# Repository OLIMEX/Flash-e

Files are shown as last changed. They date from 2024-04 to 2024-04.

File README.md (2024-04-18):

# Flash-e
External eMMC and SPI Flash module

https://www.olimex.com/Products/OLinuXino/Accessories/Flash-e32Gs16M/

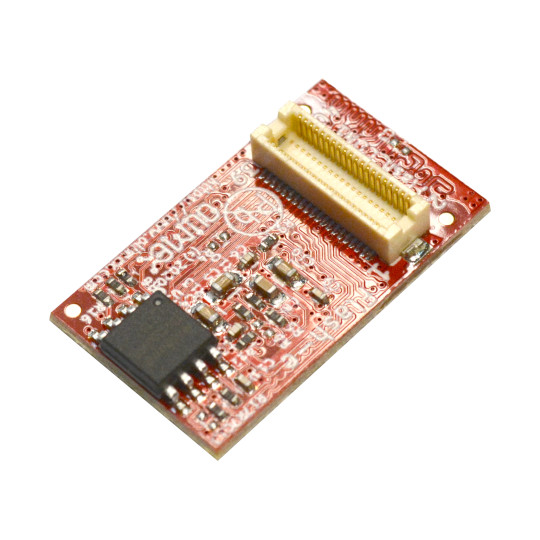
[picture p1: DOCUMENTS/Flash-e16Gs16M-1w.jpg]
Flash-e16Gs16M-1w

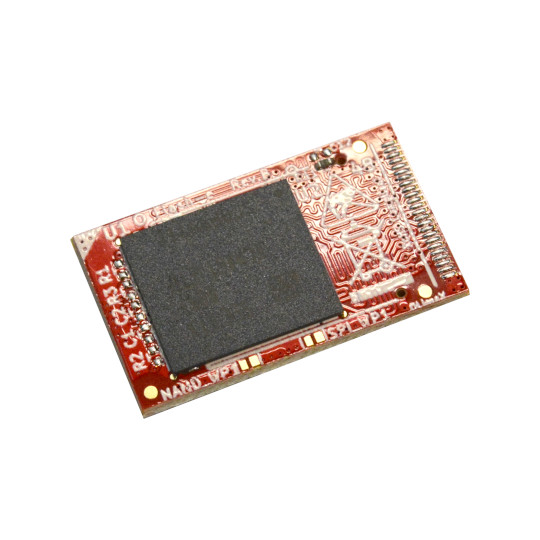
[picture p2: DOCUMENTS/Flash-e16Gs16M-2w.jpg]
Flash-e16Gs16M-2w


## Licensee
* Hardware is released under CERN Open Hardware Licence Version 2 - Strongly Reciprocal
* Software is released under GPL V3 Licensee
* Documentation is released under CC BY-SA 4.0

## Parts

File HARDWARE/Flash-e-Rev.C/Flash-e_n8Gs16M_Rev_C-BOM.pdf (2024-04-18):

Flash-e_n8Gs16M_Rev_C-BOM | 06/02/2022
Quantity | Designation | Package | Designator
3 | 22R/R0402 | R0402 | R4,R7,R8
6 | 10k/R0402 | R0402
4 | 100nF/10V/10%/X7R/C0402 | C0402 | C1,C2,C3,C11
1 | | TSOP48 | U1
1 | W25Q128JVSIQ(SOIC-8_208mils) SO-8_208mil | U3
1 | DF12(3.5)-40DP-0.5V(86) | | Flash_CON1
2 | Opened | SJ_1_SMALLER
2 | NA(22R/R0402) | R0402 | R11,R10
4 | NA(10k/R0402) | R0402
1 | NA/R0402 | R0402 | R6
3 | NA(100nF/10V/10%/X7R/C0402) | C0402 | C6,C7,C9
4 | NA(2.2uF/6.3V/10%/X5R/C0603) | C0603
2 | NA/C0402 | C0402 | C12,C13
1 | | | U2

R1,R2,R3,
R14,R16,R17

MT29F64G08CBABA-WP:B
(TSOP48)

DF12(3.5)-40DP-0.5V(86)---(CL0537-0032-4-86)

NAND_WP1,
SPI_WP1

R5,R9,R12,R13

C4,C5,C8,C10

NA(KLMAG1JETD-B041003
(FBGA153))

FBGA153_Pitch-0.5mm_
Ball-0.25mm_Dimensions-11.50x13.00x0.80mm

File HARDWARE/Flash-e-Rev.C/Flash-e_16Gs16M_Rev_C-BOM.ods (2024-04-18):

Quantity | Designation | Package | Designator
4 | 22R/R0402 | R0402 | R7,R8,R10,R11
7 | 10k/R0402 | R0402 | R5,R9,R12, R13,R14,R16,R17
4 | 100nF/10V/10%/X7R/C0402 | C0402 | C6,C7,C9,C11
4 | 2.2uF/6.3V/10%/X5R/C0603 | C0603 | C4,C5,C8,C10
1 | KLMAG1JETD-B041003(FBGA153) | FBGA153_Pitch-0.5mm_ Ball-0.25mm_Dimensions- 11.50x13.00x0.80mm | U2
1 | W25Q128JVSIQ(SOIC-8_208mils) | SO-8_208mil | U3
1 | DF12(3.5)-40DP-0.5V(86) | DF12(3.5)-40DP-0.5V(86) (CL0537-0032-4-86) | Flash_CON1
2 | Opened | SJ_1_SMALLER | NAND_WP1,SPI_WP1
1 | NA(22R/R0402) | R0402 | R4
3 | NA(10k/R0402) | R0402 | R1,R2,R3
1 | NA/R0402 | R0402 | R6
3 | NA(100nF/10V/10%/X7R/C0402) | C0402 | C1,C2,C3
2 | NA/C0402 | C0402 | C12,C13
1 | NA(MT29F64G08CBABA-WP:B (TSOP48)) | TSOP48 | U1

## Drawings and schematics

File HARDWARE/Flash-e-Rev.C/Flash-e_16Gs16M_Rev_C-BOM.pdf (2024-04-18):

## Flash-e_16Gs16M_Rev_C-BOM 06/01/2022

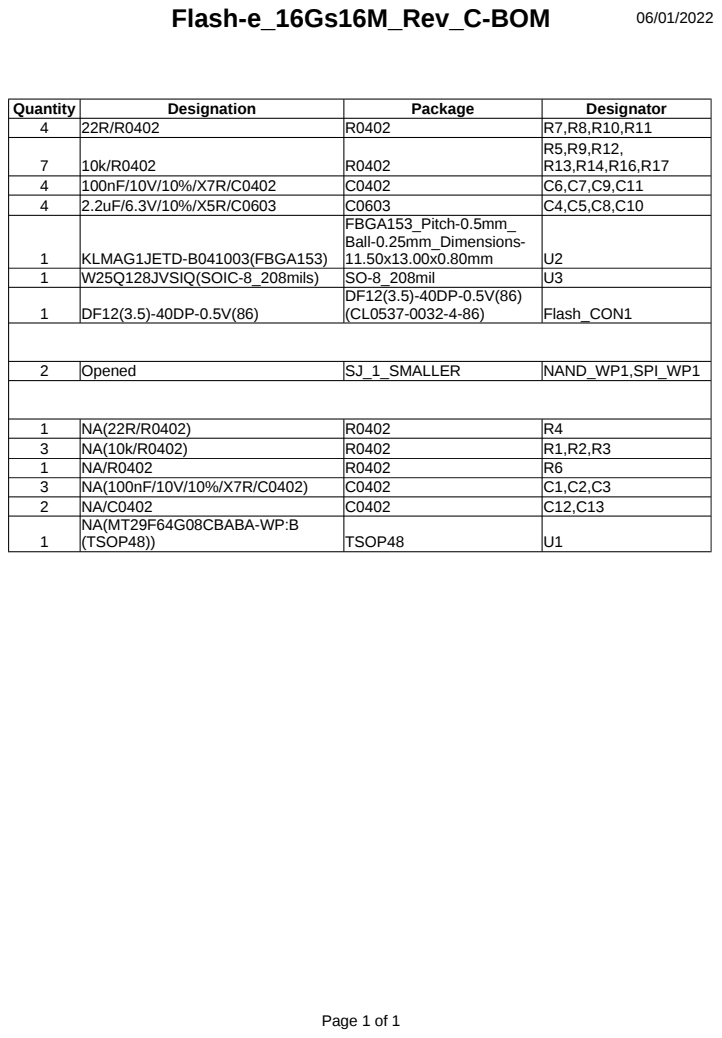
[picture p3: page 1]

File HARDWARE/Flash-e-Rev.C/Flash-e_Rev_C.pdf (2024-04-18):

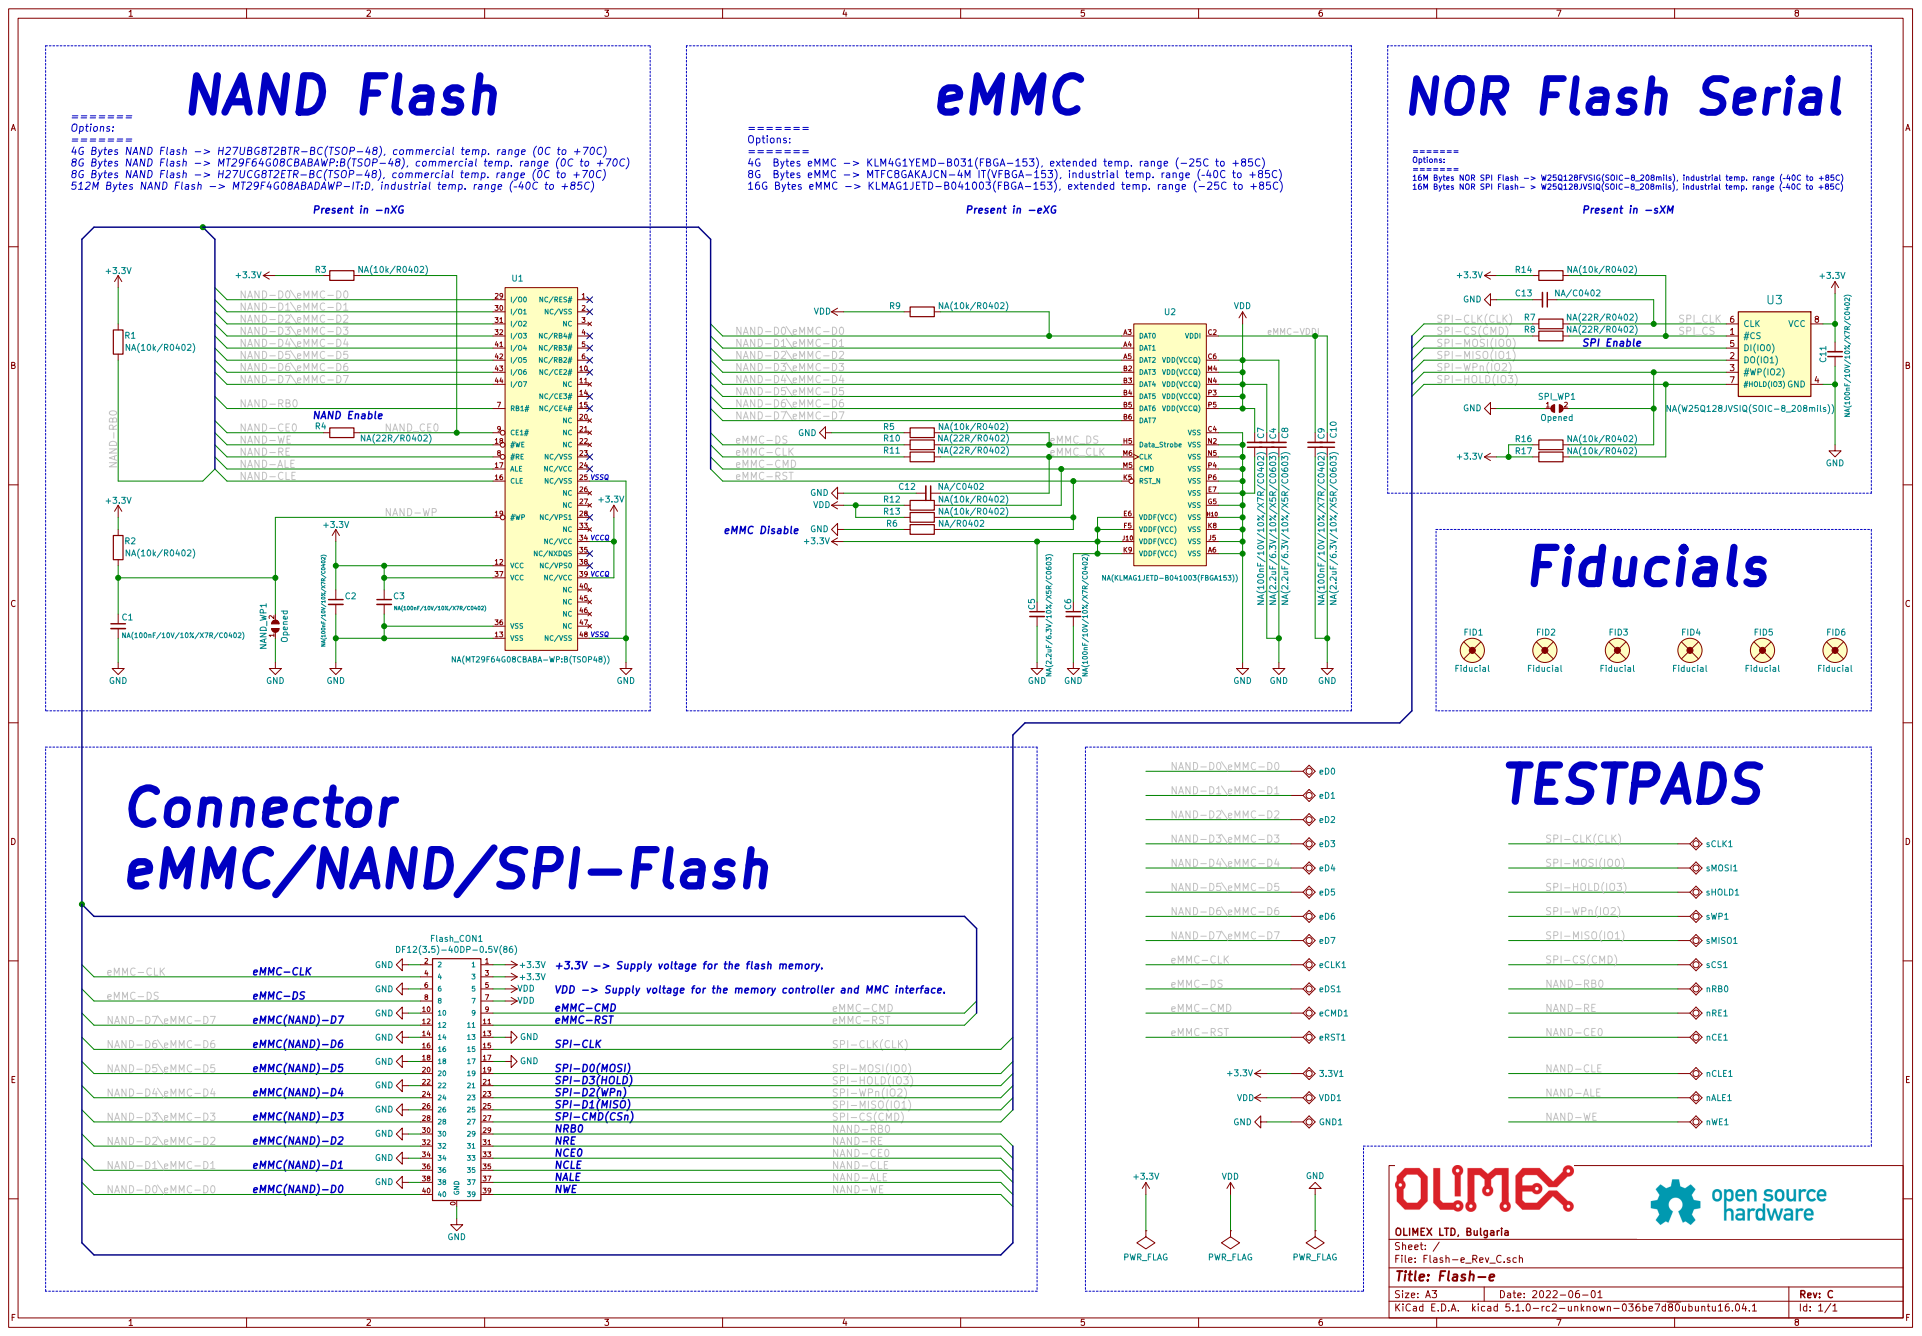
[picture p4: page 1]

4G Bytes NAND Flash -> H27UBG8T2BTR-BC(TSOP-48), commercial temp. range (0C to +70C)
8G Bytes NAND Flash -> MT29F64G08CBABAWP:B(TSOP-48), commercial temp. range (0C to +70C)
8G Bytes NAND Flash -> H27UCG8T2ETR-BC(TSOP-48), commercial temp. range (0C to +70C)

4G Bytes eMMC -> KLM4G1YEMD-B031(FBGA-153), extended temp. range (-25C to +85C)
8G Bytes eMMC -> MTFC8GAKAJCN-4M IT(VFBGA-153), industrial temp. range (40C to +85C)
+3.3V NAND-D0\eMMC-D0

16M Bytes NOR SPI Flash -> W25Q128FVSIG(SOIC-8_208mils), industrial temp. range (40C to +85C) 16M Bytes NOR SPI Flash- > W25Q128JVSIQ(SOIC-8_208mils), industrial temp. range (40C to +85C)

NAND-D0\eMMC-D0
NAND-D1\eMMC-D1
NAND-D2\eMMC-D2
NAND-D3\eMMC-D3
NAND-D4\eMMC-D4
NAND-D5\eMMC-D5
NAND-D6\eMMC-D6
NAND-D7\eMMC-D7 NAND-RB0 NAND-CE0 NAND-WE NAND-ALE NAND-CLE NAND-RE

GND GND GND GND GND GND Connector
eMMC/NAND/SPI-Flash
9 Flash_CON1 DF12(3.5)-40DP-0.5V(86) GND

SPI-CS(CMD) NAND-RB0 NAND-RE NAND-CE0

eMMC-CMD
eMMC-RST NAND-RB0 NAND-CE0 NAND-WE NAND-ALE NAND-CLE NAND-RE

NAND-CLE NAND-ALE NAND-WE

SPI-D3(HOLD) SPI-HOLD(IO3)
SPI-D2(WPn) SPI-WPn(IO2)
SPI-D1(MISO) SPI-MISO(IO1)

NRB0 NCE0 NWE NRE NALE NCLE

File: Flash-e_Rev_C.sch Sheet: / OLIMEX LTD, Bulgaria

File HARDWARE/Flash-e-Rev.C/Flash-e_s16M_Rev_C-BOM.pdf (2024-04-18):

## Flash-e_s16M_Rev_C-BOM 06/02/2022

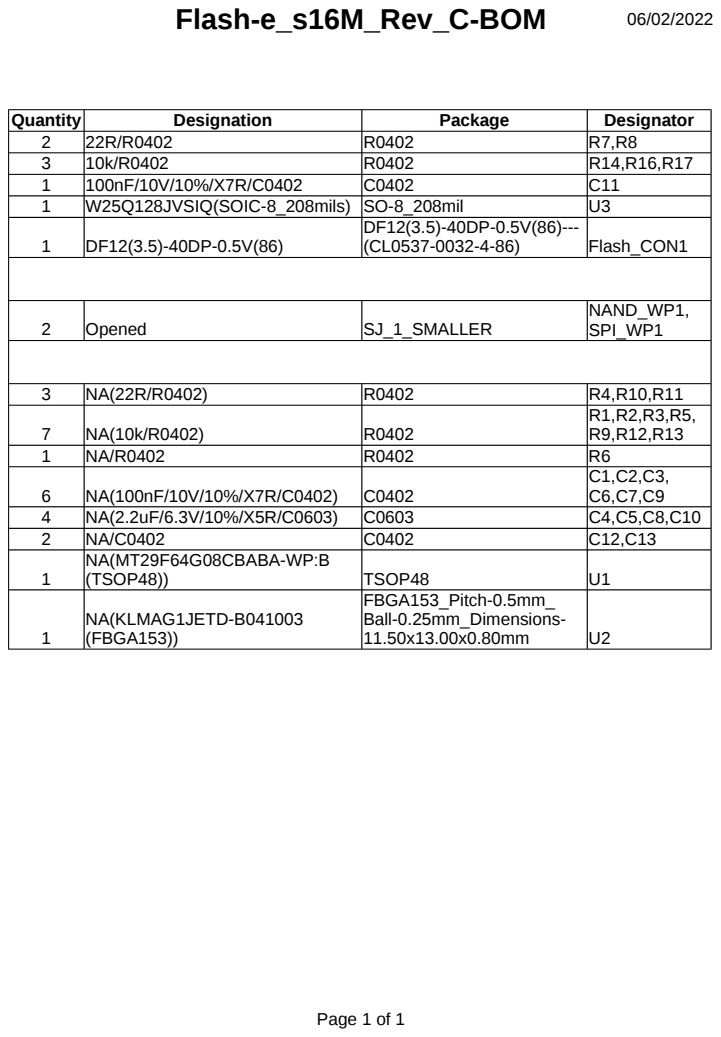
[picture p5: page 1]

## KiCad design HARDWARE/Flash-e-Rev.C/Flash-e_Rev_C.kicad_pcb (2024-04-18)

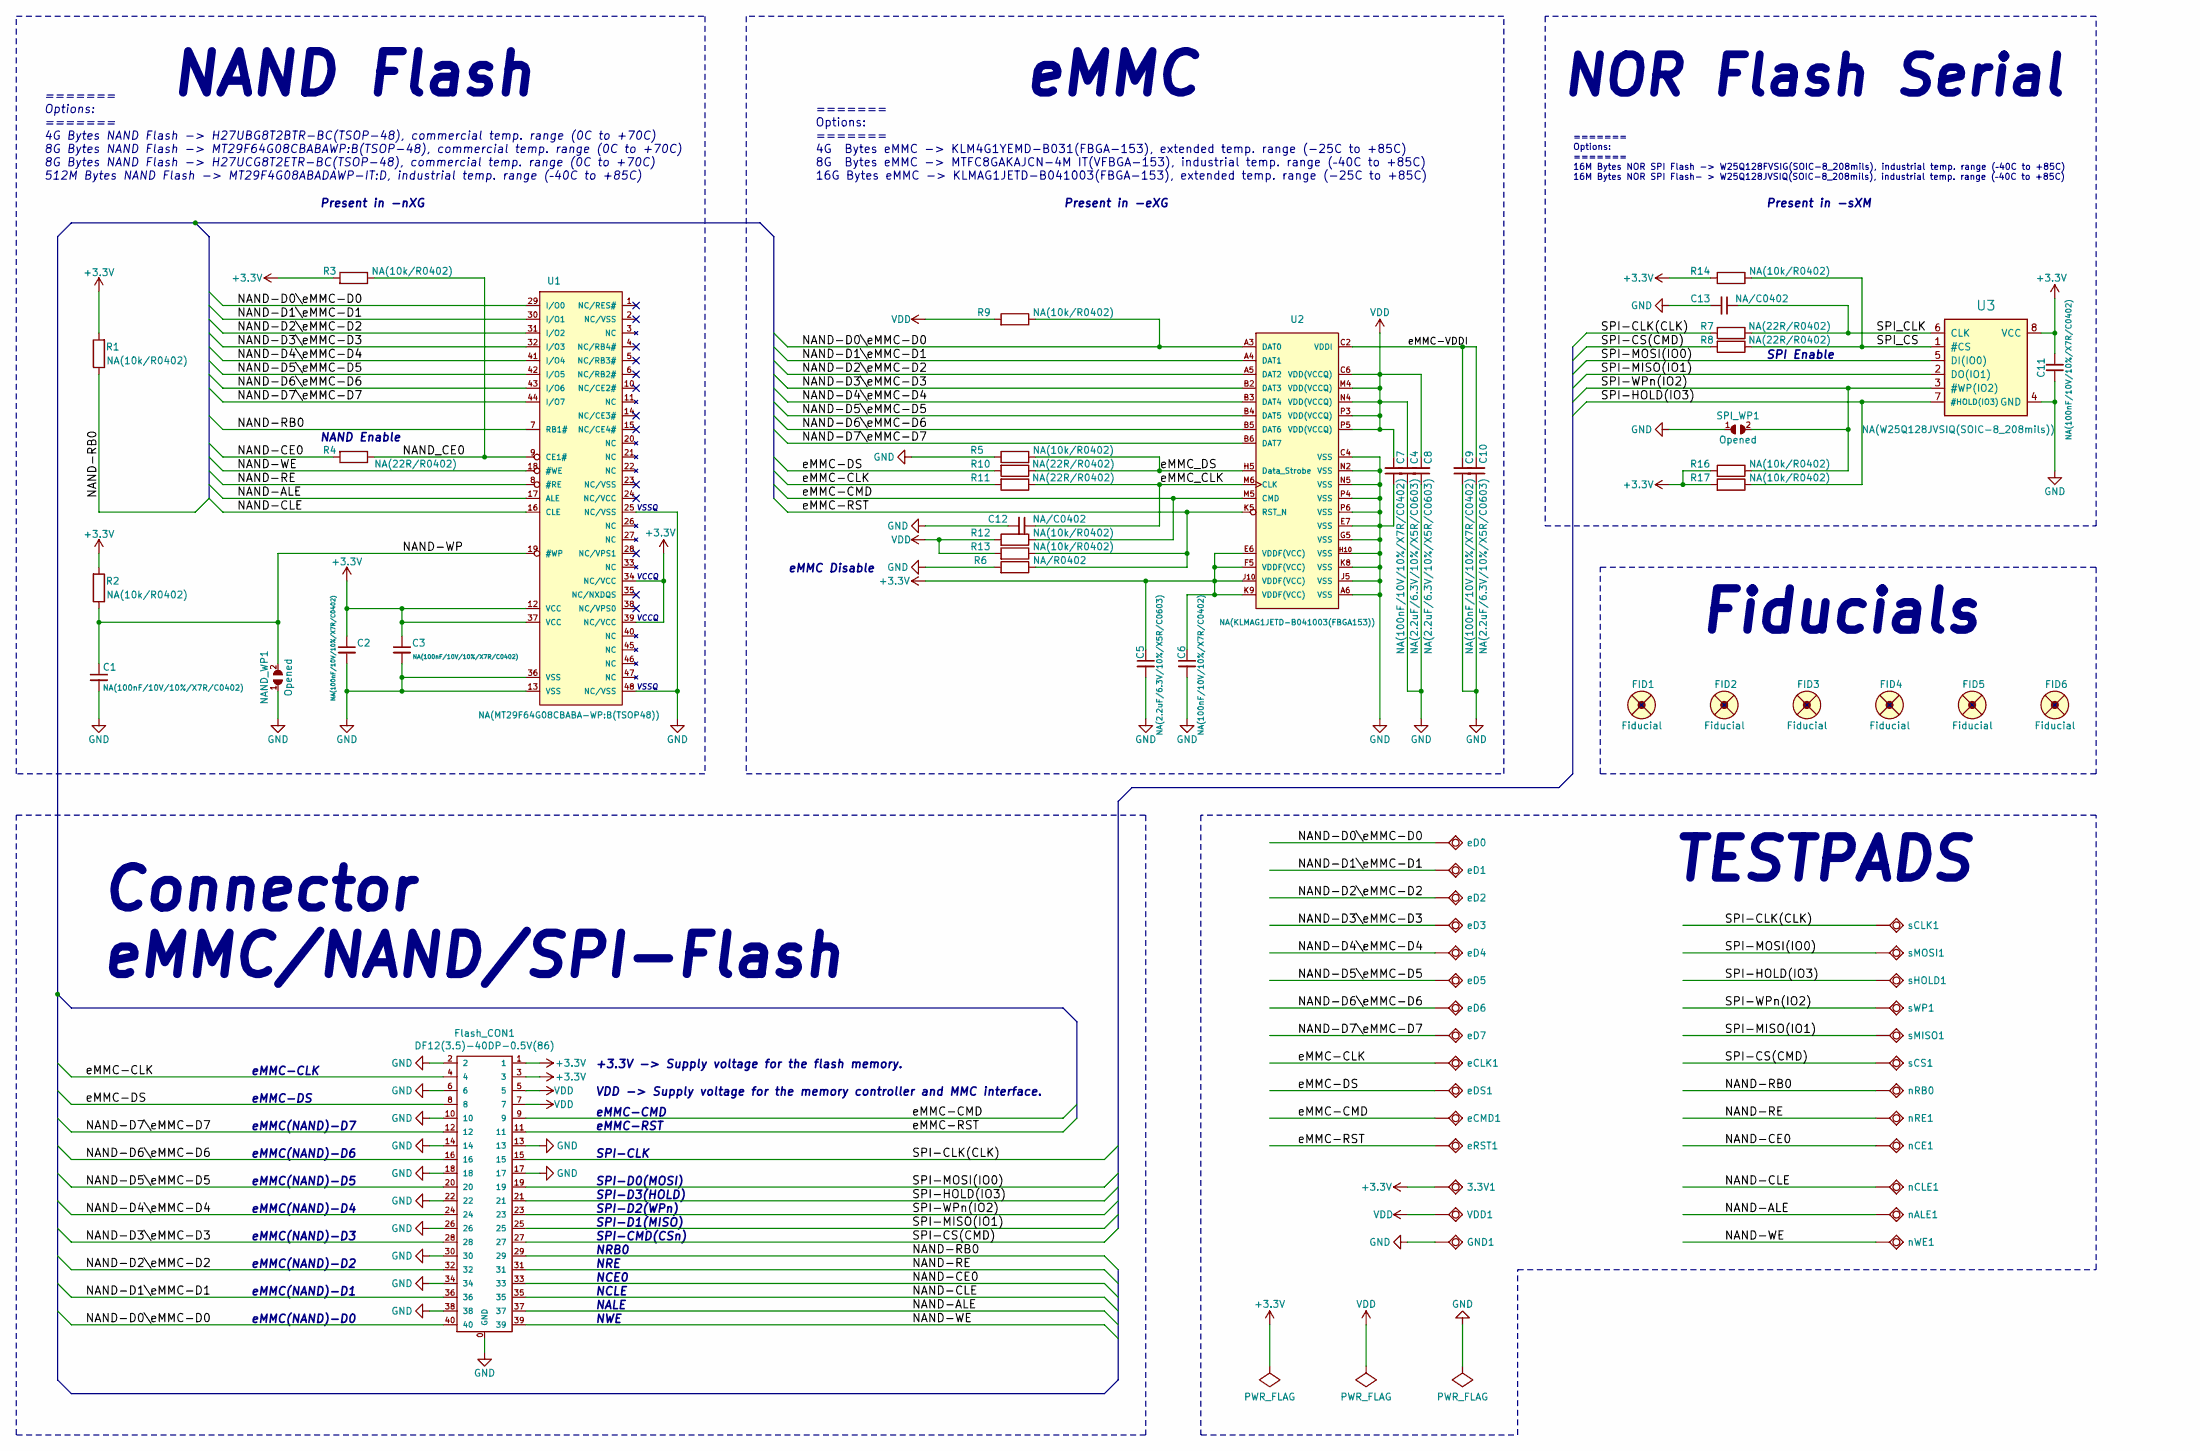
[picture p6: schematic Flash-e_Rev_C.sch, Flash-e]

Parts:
3.3V1: TESTPAD; TEST_PAD_0.6x0.9mm
C1, C2, C3, C6, C7, C9, C11: NA(100nF/10V/10%/X7R/C0402); C_0402_5MIL_DWS
C4, C5, C8, C10: NA(2.2uF/6.3V/10%/X5R/C0603); C_0603_5MIL_DWS
C12, C13: NA/C0402; C_0402_5MIL_DWS
FID1, FID2, FID3, FID4, FID5, FID6: Fiducial; Fiducial1x3
Flash_CON1: DF12(3.5)-40DP-0.5V(86); DF12(3.5)-40DP-0.5V(86)---(CL0537-0032-4-86)-0.25mm_Cream
GND1: TESTPAD; TEST_PAD_0.6x0.9mm
NAND_WP1: Opened; SJ_1_SMALLER
R1, R2, R3, R5, R9, R12, R13, R14, R16, R17: NA(10k/R0402); R_0402_5MIL_DWS
R4, R7, R8, R10, R11: NA(22R/R0402); R_0402_5MIL_DWS
R6: NA/R0402; R_0402_5MIL_DWS
SPI_WP1: Opened; SJ_1_SMALLER
U1: NA(MT29F64G08CBABA-WP:B(TSOP48)); TSOP48
U2: NA(KLMAG1JETD-B041003(FBGA153)); FBGA153_Pitch-0.5mm_Ball-0.25mm_Dimensions-11.50x13.00x0.80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
U3: NA(W25Q128JVSIQ(SOIC-8_208mils)); SO-8_208mil
VDD1: TESTPAD; TEST_PAD_0.6x0.9mm
eCLK1: TESTPAD; TEST_PAD_0.6x0.9mm
eCMD1: TESTPAD; TEST_PAD_0.6x0.9mm
eD0, eD1, eD2, eD3, eD4, eD5, eD6, eD7: TESTPAD; TEST_PAD_0.6x0.9mm
eDS1: TESTPAD; TEST_PAD_0.6x0.9mm
eRST1: TESTPAD; TEST_PAD_0.6x0.9mm
nALE1: TESTPAD; TEST_PAD_0.6x0.9mm
nCE1: TESTPAD; TEST_PAD_0.6x0.9mm
nCLE1: TESTPAD; TEST_PAD_0.6x0.9mm
nRB0: TESTPAD; TEST_PAD_0.6x0.9mm
nRE1: TESTPAD; TEST_PAD_0.6x0.9mm
nWE1: TESTPAD; TEST_PAD_0.6x0.9mm
sCLK1: TESTPAD; TEST_PAD_0.6x0.9mm
sCS1: TESTPAD; TEST_PAD_0.6x0.9mm
sHOLD1: TESTPAD; TEST_PAD_0.6x0.9mm
sMISO1: TESTPAD; TEST_PAD_0.6x0.9mm
sMOSI1: TESTPAD; TEST_PAD_0.6x0.9mm
sWP1: TESTPAD; TEST_PAD_0.6x0.9mm

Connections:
+3V3: 3.3V1.1, C2.1, C3.1, C5.1, C6.1, C11.2, Flash_CON1.1, Flash_CON1.3, R1.2, R2.2, R3.2, R14.2, R16.2, R17.2, U1.12 (VCC), U1.34 (NC/VCC), U1.37 (VCC), U1.39 (NC/VCC), U2.E6 (VDDF(VCC)), U2.F5 (VDDF(VCC)), U2.J10 (VDDF(VCC)), U2.K9 (VDDF(VCC)), U3.8 (VCC)
/NAND-ALE: Flash_CON1.37, U1.17 (ALE), nALE1.1
/NAND-CE0: Flash_CON1.33, R4.2, nCE1.1
/NAND-CLE: Flash_CON1.35, U1.16 (CLE), nCLE1.1
/NAND-D0\eMMC-D0: Flash_CON1.40, R9.1, U1.29 (I/O0), U2.A3 (DAT0), eD0.1
/NAND-D1\eMMC-D1: Flash_CON1.36, U1.30 (I/O1), U2.A4 (DAT1), eD1.1
/NAND-D2\eMMC-D2: Flash_CON1.32, U1.31 (I/O2), U2.A5 (DAT2), eD2.1
/NAND-D3\eMMC-D3: Flash_CON1.28, U1.32 (I/O3), U2.B2 (DAT3), eD3.1
/NAND-D4\eMMC-D4: Flash_CON1.24, U1.41 (I/O4), U2.B3 (DAT4), eD4.1
/NAND-D5\eMMC-D5: Flash_CON1.20, U1.42 (I/O5), U2.B4 (DAT5), eD5.1
/NAND-D6\eMMC-D6: Flash_CON1.16, U1.43 (I/O6), U2.B5 (DAT6), eD6.1
/NAND-D7\eMMC-D7: Flash_CON1.12, U1.44 (I/O7), U2.B6 (DAT7), eD7.1
/NAND-RB0: Flash_CON1.29, R1.1, U1.7 (RB1#), nRB0.1
/NAND-RE: Flash_CON1.31, U1.8 (#RE), nRE1.1
/NAND-WE: Flash_CON1.39, U1.18 (#WE), nWE1.1
/NAND-WP: C1.1, NAND_WP1.2, R2.1, U1.19 (#WP)
/NAND_CE0: R3.1, R4.1, U1.9 (CE1#)
/SPI-CLK(CLK): Flash_CON1.15, R7.2, sCLK1.1
/SPI-CS(CMD): Flash_CON1.27, R8.2, sCS1.1
/SPI-HOLD(IO3): Flash_CON1.21, R17.1, U3.7 (#HOLD(IO3)), sHOLD1.1
/SPI-MISO(IO1): Flash_CON1.25, U3.2 (DO(IO1)), sMISO1.1
/SPI-MOSI(IO0): Flash_CON1.19, U3.5 (DI(IO0)), sMOSI1.1
/SPI-WPn(IO2): Flash_CON1.23, R16.1, SPI_WP1.2, U3.3 (#WP(IO2)), sWP1.1
/SPI_CLK: C13.1, R7.1, U3.6 (CLK)
/SPI_CS: R8.1, R14.1, U3.1 (#CS)
/eMMC-CLK: Flash_CON1.4, R11.2, eCLK1.1
/eMMC-CMD: Flash_CON1.9, R12.1, U2.M5 (CMD), eCMD1.1
/eMMC-DS: Flash_CON1.8, R10.2, eDS1.1
/eMMC-RST: Flash_CON1.11, R6.1, R13.1, U2.K5 (RST_N), eRST1.1
/eMMC-VDDI: C9.2, C10.2, U2.C2 (VDDI)
/eMMC_CLK: C12.1, R11.1, U2.M6 (CLK)
/eMMC_DS: R5.2, R10.1, U2.H5 (Data_Strobe)
GND: C1.2, C2.2, C3.2, C4.1, C5.2, C6.2, C7.1, C8.1, C9.1, C10.1, C11.1, C12.2, C13.2, Flash_CON1.0 (GND), Flash_CON1.2, Flash_CON1.6, Flash_CON1.10, Flash_CON1.13, Flash_CON1.14, Flash_CON1.17, Flash_CON1.18, Flash_CON1.22, Flash_CON1.26, Flash_CON1.30, Flash_CON1.34, Flash_CON1.38, GND1.1, NAND_WP1.1, R5.1, R6.2, SPI_WP1.1, U1.13 (VSS), U1.25 (NC/VSS), U1.36 (VSS), U1.48 (NC/VSS), U2.A6 (VSS), U2.C4 (VSS), U2.E7 (VSS), U2.G5 (VSS), U2.H10 (VSS), U2.J5 (VSS), U2.K8 (VSS), U2.N2 (VSS), U2.N5 (VSS), U2.P4 (VSS), U2.P6 (VSS), U3.4 (GND)
VDD: C4.2, C7.2, C8.2, Flash_CON1.5, Flash_CON1.7, R9.2, R12.2, R13.2, U2.C6 (VDD(VCCQ)), U2.M4 (VDD(VCCQ)), U2.N4 (VDD(VCCQ)), U2.P3 (VDD(VCCQ)), U2.P5 (VDD(VCCQ)), VDD1.1

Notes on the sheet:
NAND Flash
Present in -nXG
NOR Flash Serial
eMMC
Present in -eXG
Present in -sXM
======= Options: ======= 4G Bytes eMMC -> KLM4G1YEMD-B031(FBGA-153), extended temp. range (-25C to +85C) 8G Bytes eMMC -> MTFC8GAKAJCN-4M IT(VFBGA-153), industrial temp. range (–40C to +85C) 16G Bytes eMMC -> KLMAG1JETD-B041003(FBGA-153), extended temp. range (-25C to +85C)
eMMC(NAND)-D0
eMMC(NAND)-D1
eMMC(NAND)-D2
eMMC(NAND)-D3
eMMC-CLK
Connector eMMC/NAND/SPI-Flash
eMMC(NAND)-D5
eMMC(NAND)-D7
eMMC(NAND)-D6
eMMC-DS
eMMC(NAND)-D4
NAND Enable
eMMC Disable
SPI Enable
Fiducials
======= Options: ======= 4G Bytes NAND Flash -> H27UBG8T2BTR-BC(TSOP-48), commercial temp. range (0C to +70C) 8G Bytes NAND Flash -> MT29F64G08CBABAWP:B(TSOP-48), commercial temp. range (0C to +70C) 8G Bytes NAND Flash -> H27UCG8T2ETR-BC(TSOP-48), commercial temp. range (0C to +70C) 512M Bytes NAND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
eMMC-CMD
NRB0
NCE0
NWE
NRE
NALE
NCLE
SPI-CMD(CSn)
SPI-CLK
SPI-D3(HOLD)
SPI-D2(WPn)
SPI-D1(MISO)
SPI-D0(MOSI)
VDD -> Supply voltage for the memory controller and MMC interface.
+3.3V -> Supply voltage for the flash memory.
eMMC-RST
VSSQ

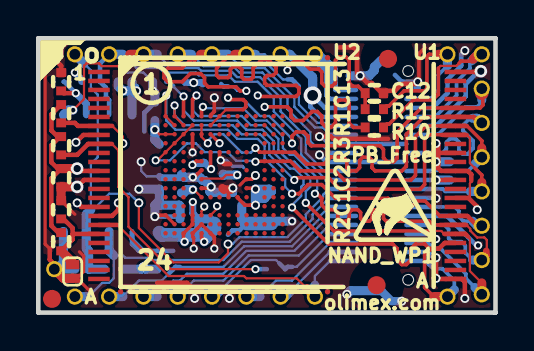
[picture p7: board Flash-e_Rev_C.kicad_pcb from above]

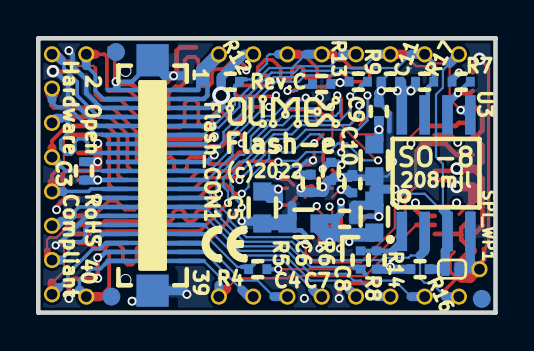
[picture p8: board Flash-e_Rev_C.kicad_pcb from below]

Board: 4 copper layers, 25.4 x 15.2 mm, 71 parts (28 on the bottom side), 34 nets.

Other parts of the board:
Logo_OLimeX: LOGO_OLIMEX_80
Sign_Antistatic: LOGO_ANTISTATIC_SMALL_4.5mmX2.8mm
Sign_CE_Small: CE_Sign_Small

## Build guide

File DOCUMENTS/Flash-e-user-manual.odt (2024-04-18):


Flash-eXXGs16M

User Manual

Rev.1.0 April 2024 olimex.com

# What is Flash-e16Gs16M

Flash-e16Gs16M (https://www.olimex.com/Products/OLinuXino/Accessories/Flash-e16Gs16M/) is an open source hardware board which adds external eMMC and SPI Flash to Olimex’s OLinuXino and SOM modules which are compatible with it.

For the moment these are:

STMP157-OLinuXino-LIME2 (https://www.olimex.com/Products/OLinuXino/STMP1/STMP157-OLinuXino-LIME2/open-source-hardware)

A20-OLinuXino-LIME2 (https://www.olimex.com/Products/OLinuXino/A20/A20-OLinuXino-LIME2/open-source-hardware) Rev.N

STMP157-BASE-SOM-EVB (https://www.olimex.com/Products/SOM/STMP1/STMP157-BASE-SOM-EVB/open-source-hardware)

STMP1-A13—EVB (https://www.olimex.com/Products/SOM/STMP1/STMP1-A13--EVB/open-source-hardware)

iMX8MP-SOM-EVB

S3-OLinuXino

and others to come

# Flash-eXXGs16M features:

- eMMC 5.0 16GB or 32GB
- SPI flash 16MB
- Dimensions are: 25 x 15 mm

# Order codes for Flash-eXXGs16M:

Flash-e16Gs16M (https://www.olimex.com/Products/OLinuXino/Accessories/Flash-e16Gs16M/) Flash module with 16GB eMMC Flash and 16MB SPI Flash

Flash-e32Gs16M (https://www.olimex.com/Products/OLinuXino/Accessories/Flash-e32Gs16M/) Flash module with 32GB eMMC Flash and 16MB SPI Flash

# HARDWARE

## Flash-eXXGs16MB layout:

connector

SPI Flash


Orientation mark

eMMC

## Flash-eXXs16M schematics:

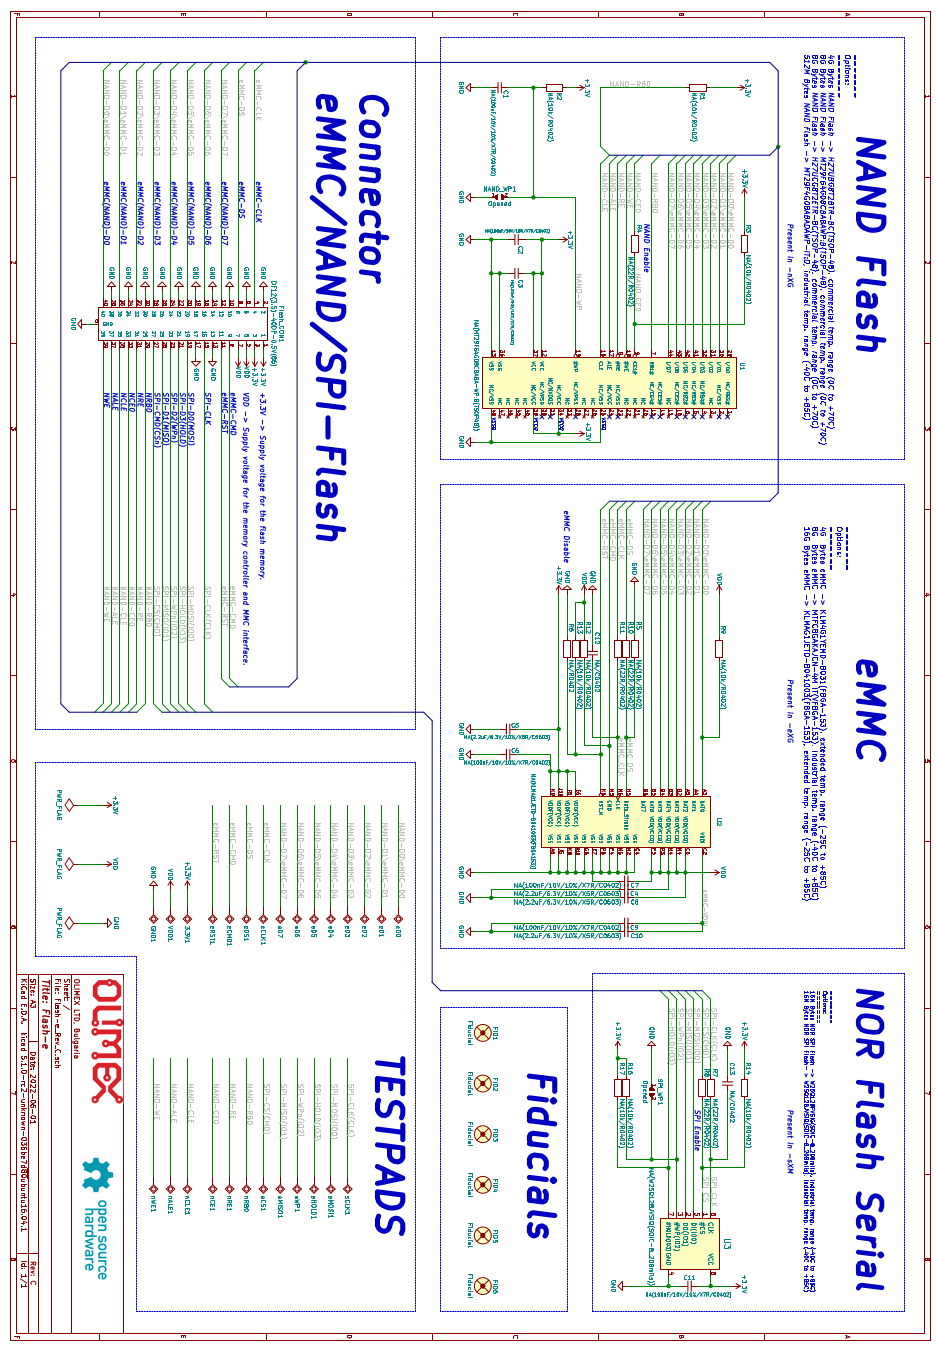
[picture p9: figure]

# Revision History

Revision 1.0 April 2024

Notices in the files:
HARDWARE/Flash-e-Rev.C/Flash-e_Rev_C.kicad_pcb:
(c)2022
